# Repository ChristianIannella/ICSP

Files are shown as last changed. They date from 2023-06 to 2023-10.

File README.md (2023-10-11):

# ICSP
[Buy on Tindie](https://www.tindie.com/products/chris_maker_/attiny85-uploader/)

<picture><picture>

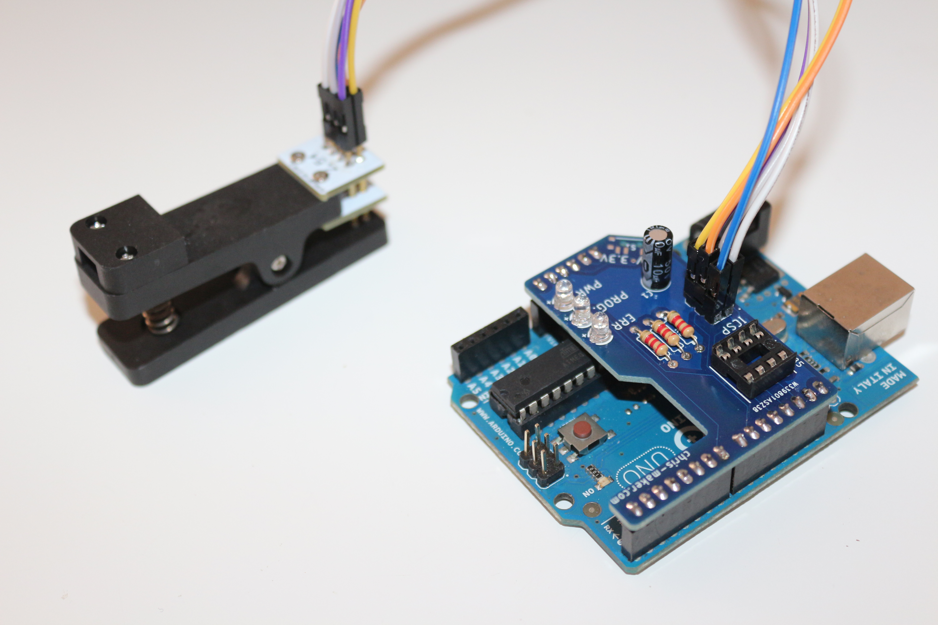
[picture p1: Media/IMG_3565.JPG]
ICSP Iannella Christian


Con questo shield è possibile caricare il bootloader Arduino su microcontrollori come l'Atmega329P (Arduino Uno) o quelli della famiglia Attiny, è anche possibile
caricare il tuo sketch senza bisogno di interfaccia USB/UART.
Lo shield dispone di zoccolo per programmare un Attiny85 DIP, a bordo sono presenti tre led di segnalazione: **Power**, **Programming** e **Error**. 

Prima di tutto dovrai caricare su una scheda Arduino UNO lo sketch **ArduinoISP** che trovi nella sezione **Esempi** 

Ecco il pinout della porta ICSP e il pinout di alcuni uC.

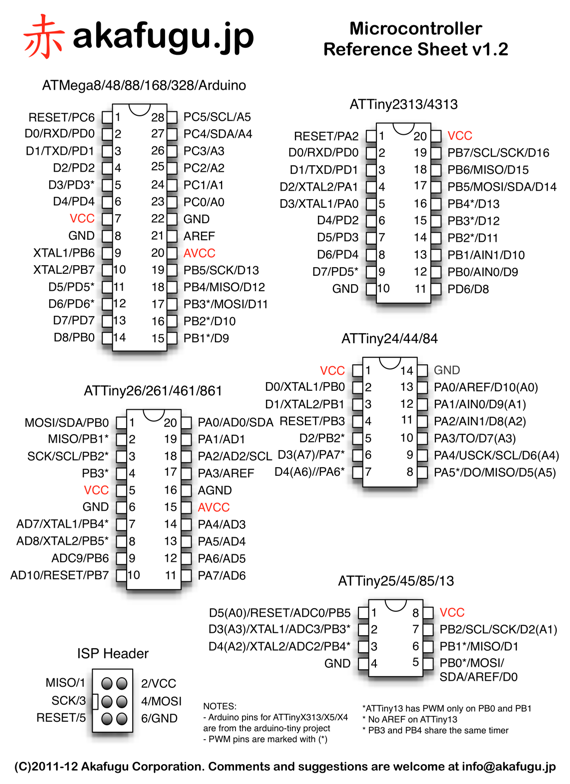
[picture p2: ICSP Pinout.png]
ICSP Pinout


# ATMEGA328P

- Avvia l'IDE Arduino
- Dal menu **Strumenti** seleziona la scheda **Arduino Nano** o **Arduino Uno**
- Dal menu **Strumenti** seleziona **Programmatore** **ArduinoISP**
- Ora dovrai scrivere il bootloader dal menu **Strumenti** e cliccando su **Scrivi il bootloader**
- Fatto questo non ti resta che caricare il tuo sketch dal menu **Sketch** cliccando su **Carica tramite programmatore**

# ATTINY85

- Avvia l'IDE Arduino
- Vai in **Impostazioni** e aggiungi il seguente URL nell'apposito spazio: 
https://raw.githubusercontent.com/damellis/attiny/ide-1.6.x-boards-manager/package_damellis_attiny_index.json
- Dal **Gestore schede** cerca "Attiny" e installa i files.
- Dal menu **Strumenti** seleziona la scheda **Attiny25/45/85**
- Dal menu **Strumenti** seleziona **Programmatore** **ArduinoISP**
- Ora dovrai scrivere il bootloader dal menu **Strumenti** e cliccando su **Scrivi il bootloader**
- Fatto questo non ti resta che caricare il tuo sketch dal menu **Sketch** cliccando su **Carica tramite programmatore**

Provalo con [Dice keychain](https://www.tindie.com/products/chris_maker_/attiny85-keychain-dice/)

# Contribute
Please, feel free to contribute.

# Author
Iannella Christian

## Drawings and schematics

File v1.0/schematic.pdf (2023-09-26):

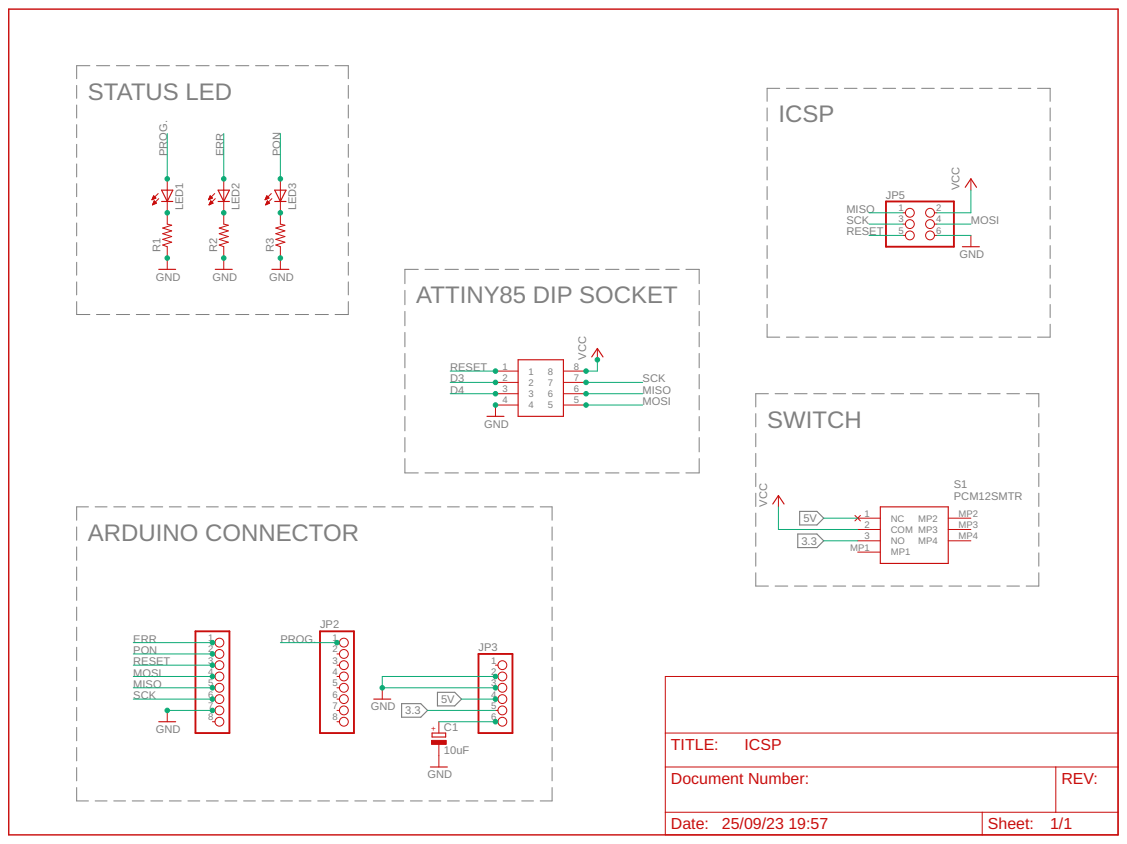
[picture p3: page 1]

Document Number: | REV:

Date: 25/09/23 19:57 | Sheet: 1/1

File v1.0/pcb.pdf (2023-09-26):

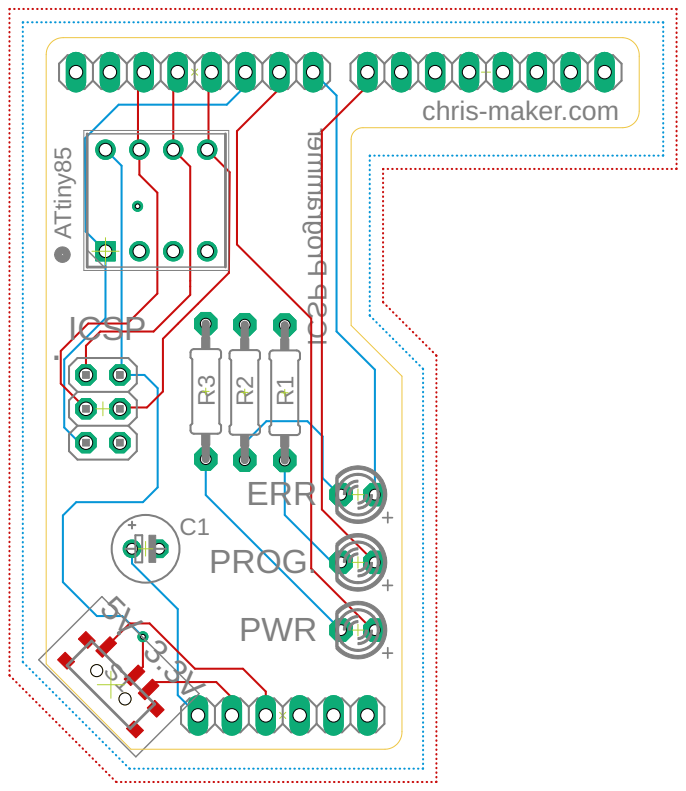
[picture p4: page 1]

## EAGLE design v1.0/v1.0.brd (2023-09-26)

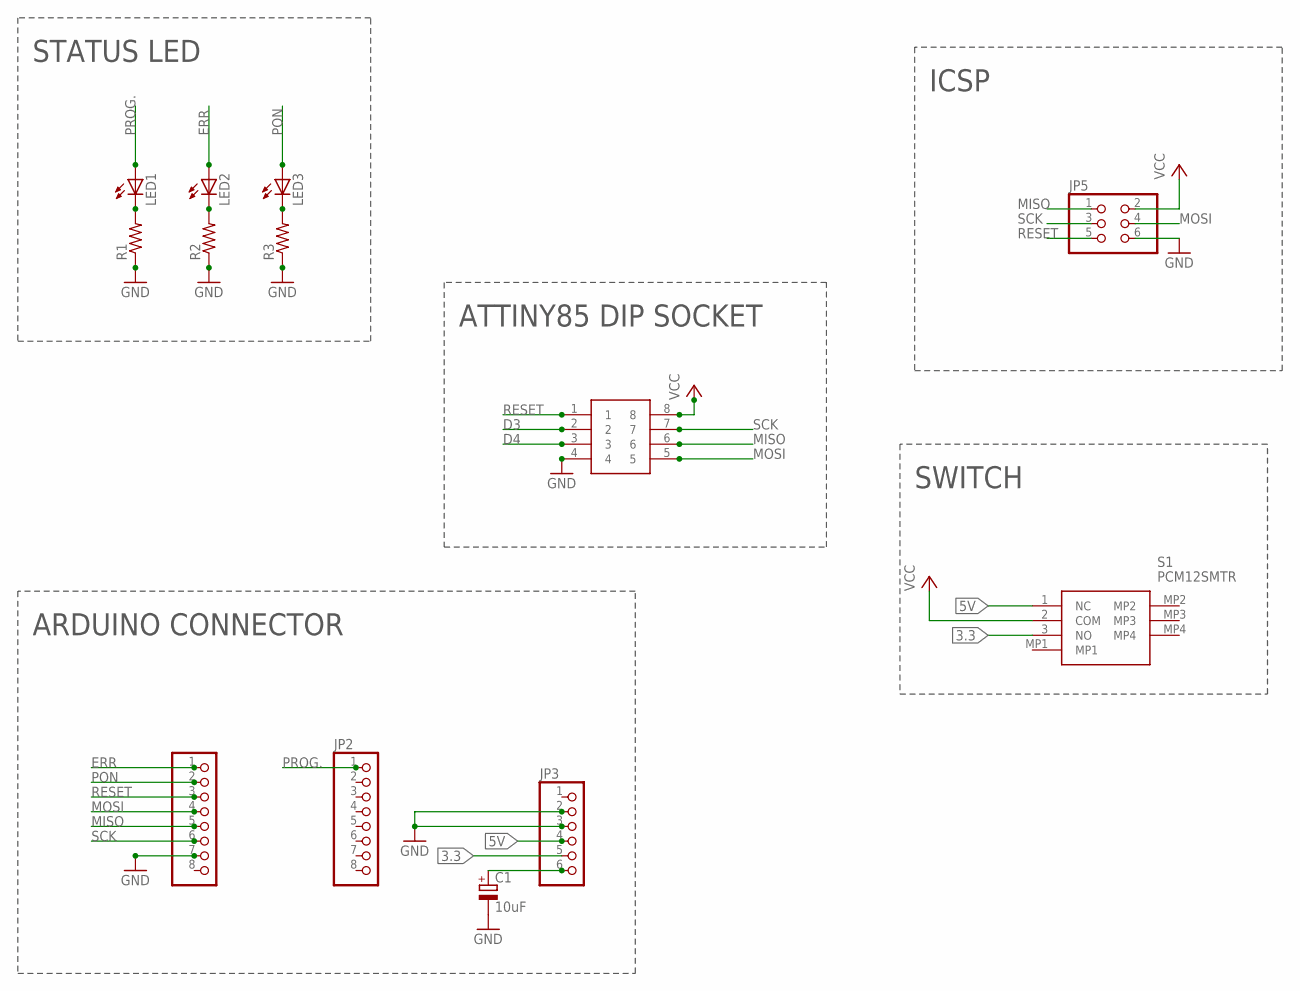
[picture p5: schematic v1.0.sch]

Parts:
C1: 10uF; E2-5
IC1: 1-2199298-2; DIPS762W70P254L1016H510Q8N
JP2, JP4: PINHD-1X8; 1X08
JP3: PINHD-1X6; 1X06
JP5: PINHD-2X3; 2X03
LED1, LED2, LED3: LED3MM
R1, R2, R3: R-US_0207/10; 0207/10
S1: PCM12SMTR

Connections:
3.3: JP3.5, S1.3 (NO)
5V: JP3.4, S1.1 (NC)
D3: IC1.2
D4: IC1.3
ERR: JP4.1, LED2.A
GND: C1.-, IC1.4, JP3.2, JP3.3, JP4.7, JP5.6, R1.1, R2.1, R3.1
MISO: IC1.6, JP4.5, JP5.1
MOSI: IC1.5, JP4.4, JP5.4
unnamed: C1.+, JP3.6
unnamed: LED1.K (C), R1.2
unnamed: LED2.K (C), R2.2
unnamed: LED3.K (C), R3.2
PON: JP4.2, LED3.A
PROG.: JP2.1, LED1.A
RESET: IC1.1, JP4.3, JP5.5
SCK: IC1.7, JP4.6, JP5.3
VCC: IC1.8, JP5.2, S1.2 (COM)

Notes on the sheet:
STATUS LED
ARDUINO CONNECTOR
ATTINY85 DIP SOCKET
ICSP
SWITCH

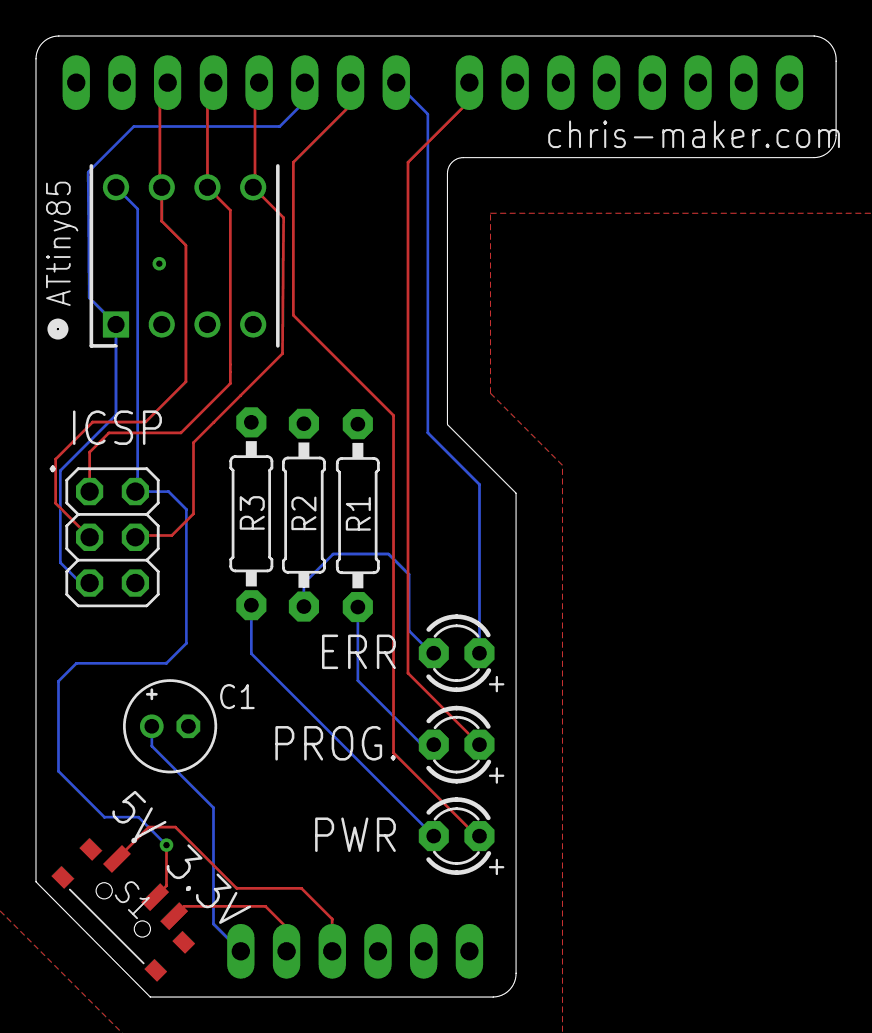
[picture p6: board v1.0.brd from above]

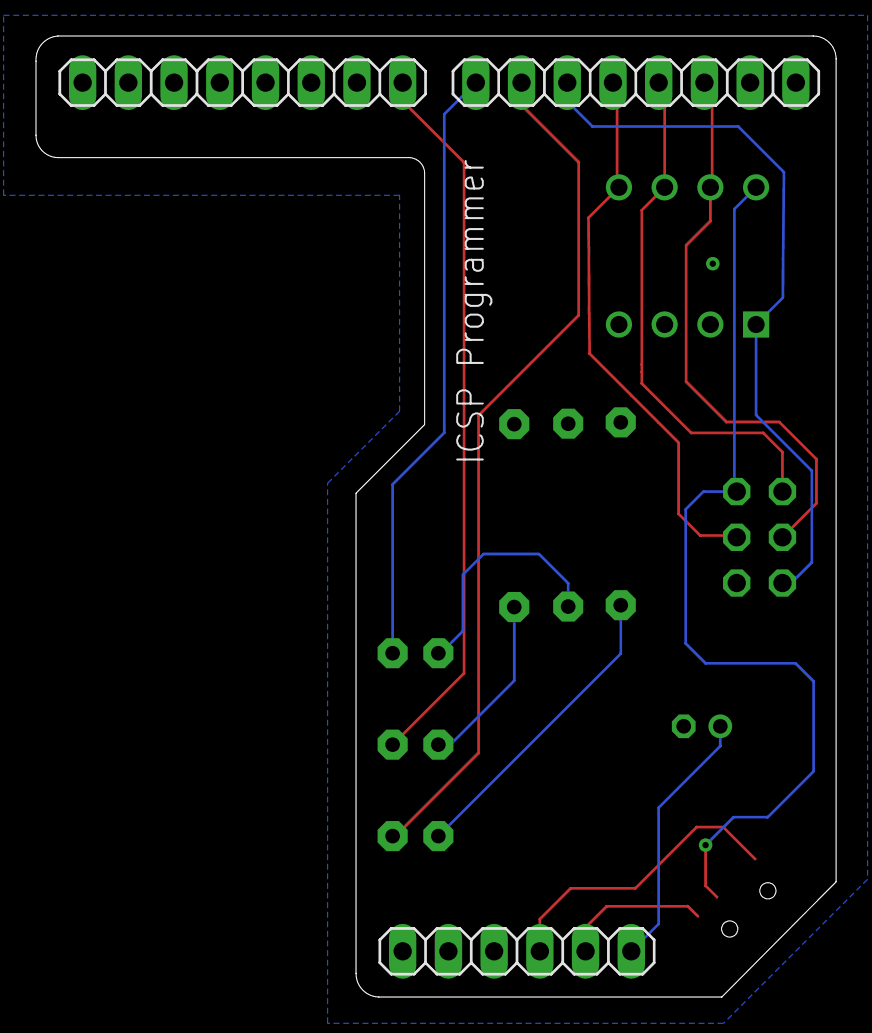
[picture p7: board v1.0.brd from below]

Board: 2 copper layers, 44.5 x 53.4 mm, 13 parts (3 on the bottom side), 15 nets.
